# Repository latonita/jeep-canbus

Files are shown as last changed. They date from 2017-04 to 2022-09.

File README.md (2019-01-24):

# jeep-canbus  Analytics (https://github.com/igrigorik/ga-beacon) 

Projects around CAN BUS in Chrysler Jeep - VES enabler, other small features

PCB for Aux + bluetooth based on xs3868 v3.0 added.

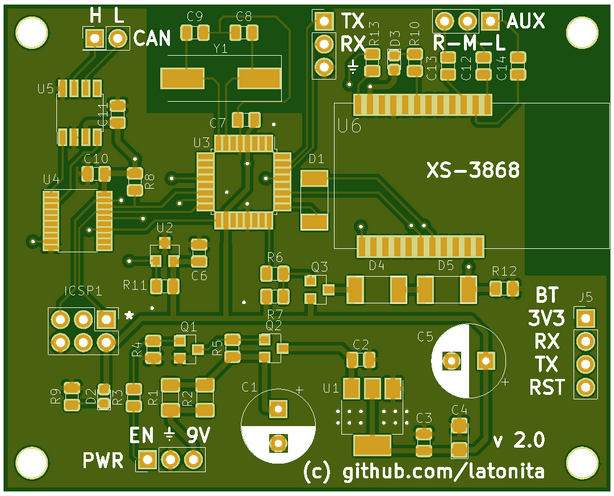
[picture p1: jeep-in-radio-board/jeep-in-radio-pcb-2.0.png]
PCBv2.0


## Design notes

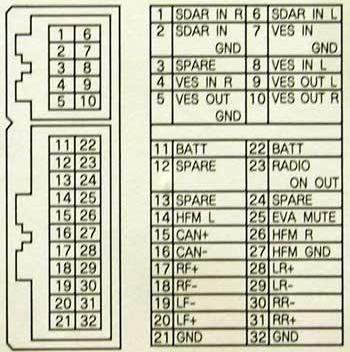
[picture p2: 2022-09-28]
jeep WH radio pinout.jpg

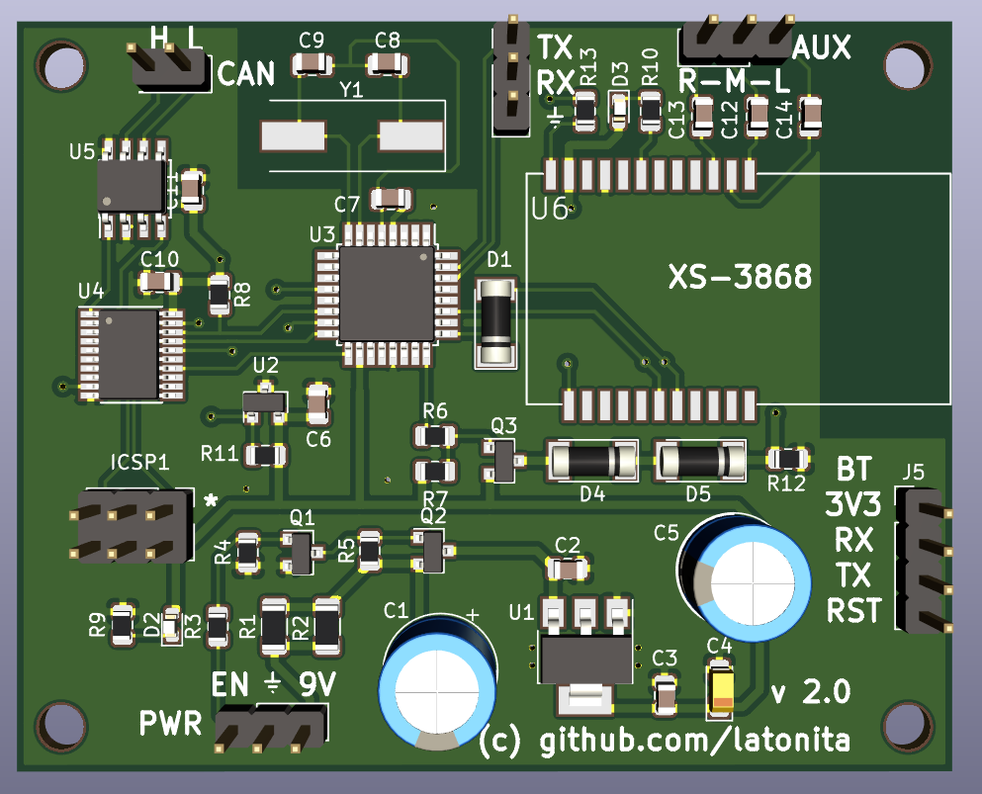
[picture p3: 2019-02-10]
jeep-in-radio-board/jeep-in-radio-pcb-2.1.png

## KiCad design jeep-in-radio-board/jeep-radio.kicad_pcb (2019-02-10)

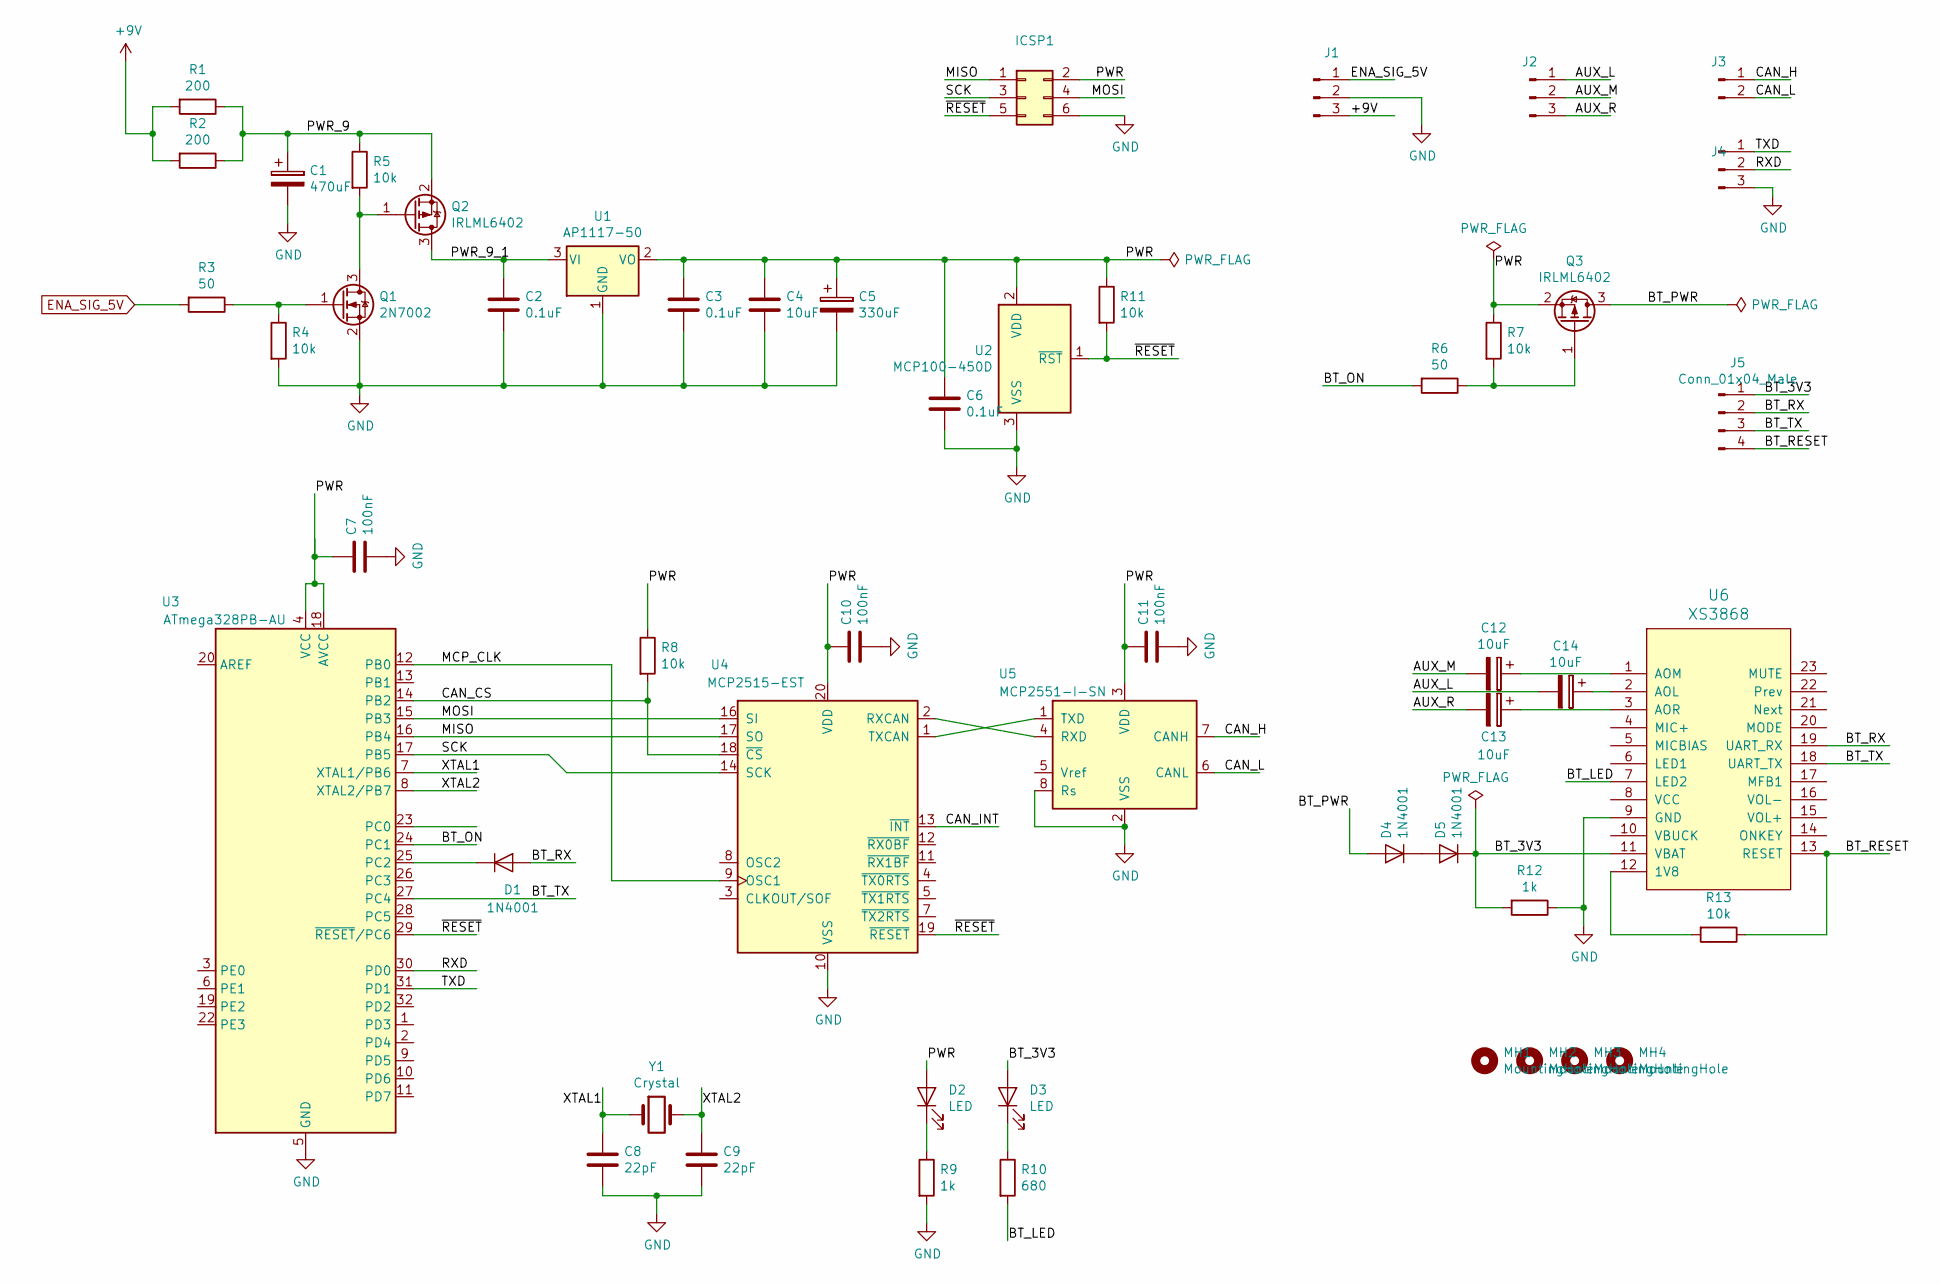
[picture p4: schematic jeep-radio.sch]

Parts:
C1: 470uF; CP_Radial_D8.0mm_P3.80mm
C2, C3, C6: 0.1uF; C_0805_2012Metric
C4: 10uF; CP_EIA-3216-18_Kemet-A
C5: 330uF; CP_Radial_D8.0mm_P3.80mm
C7, C10, C11: 100nF; C_0805_2012Metric
C8, C9: 22pF; C_0805_2012Metric
C12, C13, C14: 10uF; C_0805_2012Metric
D1, D4, D5: 1N4001; D_MELF
D2, D3: LED; LED_0603_1608Metric
ICSP1: Conn_02x03_Odd_Even; PinHeader_2x03_P2.54mm_Vertical
J1, J2, J4: Conn_01x03_Male; PinHeader_1x03_P2.54mm_Vertical
J3: Conn_01x02_Male; PinHeader_2x01_P2.54mm_Vertical
J5: Conn_01x04_Male; PinHeader_1x04_P2.54mm_Vertical
MH1, MH2, MH3, MH4: MountingHole; MountingHole_3.2mm_M3_DIN965
Q1: 2N7002; SOT-23
Q2, Q3: IRLML6402; SOT-23
R1, R2: 200; R_1206_3216Metric
R3, R6: 50; R_0805_2012Metric
R4, R5, R7, R8, R11, R13: 10k; R_0805_2012Metric
R9, R12: 1k; R_0805_2012Metric
R10: 680; R_0805_2012Metric
U1: AP1117-50; SOT-223-3_TabPin2
U2: MCP100-450D; SOT-23
U3: ATmega328PB-AU; TQFP-32_7x7mm_P0.8mm
U4: MCP2515-EST; TSSOP-20_4.4x6.5mm_P0.65mm
U5: MCP2551-I-SN; SOIC-8_3.9x4.9mm_P1.27mm
U6: XS3868
Y1: Crystal; Crystal_SMD_HC49-SD

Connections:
+9V: J1.3, R1.2, R2.2
/AUX_L: C14.2, J2.1
/AUX_M: C12.2, J2.2
/AUX_R: C13.2, J2.3
/BT_3V3: D3.2 (A), D5.1 (K), J5.1, R12.2, U6.11 (VBAT)
/BT_LED: R10.2, U6.7 (LED2)
/BT_ON: R6.2, U3.24 (PC1)
/BT_PWR: D4.2 (A), Q3.3 (D)
/BT_RESET: J5.4, R13.1, U6.13 (RESET)
/BT_RX: D1.2 (A), J5.2, U6.19 (UART_RX)
/BT_TX: J5.3, U3.27 (PC4), U6.18 (UART_TX)
/CAN_CS: R8.2, U3.14 (PB2), U4.18 (~CS)
/CAN_H: J3.1, U5.7 (CANH)
/CAN_INT: U4.13 (~INT)
/CAN_L: J3.2, U5.6 (CANL)
/MCP_CLK: U3.12 (PB0), U4.9 (OSC1)
/MISO: ICSP1.1, U3.16 (PB4), U4.17 (SO)
/MOSI: ICSP1.4, U3.15 (PB3), U4.16 (SI)
/PWR: C3.1, C4.1, C5.1, C6.1, C7.1, C10.1, C11.1, D2.2 (A), ICSP1.2, Q3.2 (S), R7.1, R8.1, R11.1, U1.2 (VO), U2.2 (VDD), U3.4 (VCC), U3.18 (AVCC), U4.20 (VDD), U5.3 (VDD)
/PWR_9: C1.1, Q2.2 (S), R1.1, R2.1, R5.1
/PWR_9_1: C2.1, Q2.3 (D), U1.3 (VI)
/RXD: J4.2, U3.30 (PD0)
/SCK: ICSP1.3, U3.17 (PB5), U4.14 (SCK)
/TXD: J4.1, U3.31 (PD1)
/XTAL1: C8.1, U3.7 (XTAL1/PB6), Y1.1
/XTAL2: C9.1, U3.8 (XTAL2/PB7), Y1.2
/~RESET~: ICSP1.5, R11.2, U2.1 (~RST), U3.29 (~RESET~/PC6), U4.19 (~RESET)
ENA_SIG_5V: J1.1, R3.2
GND: C1.2, C2.2, C3.2, C4.2, C5.2, C6.2, C7.2, C8.2, C9.2, C10.2, C11.2, ICSP1.6, J1.2, J4.3, Q1.2 (S), R4.2, R9.2, R12.1, U1.1 (GND), U2.3 (VSS), U3.5 (GND), U3.21 (GND), U4.10 (VSS), U5.2 (VSS), U5.8 (Rs), U6.9 (GND)
unnamed: C12.1, U6.1 (AOM)
unnamed: C13.1, U6.3 (AOR)
unnamed: C14.1, U6.2 (AOL)
unnamed: D1.1 (K), U3.25 (PC2)
unnamed: D2.1 (K), R9.1
unnamed: D3.1 (K), R10.1
unnamed: D4.1 (K), D5.2 (A)
unnamed: Q1.1 (G), R3.1, R4.1
unnamed: Q1.3 (D), Q2.1 (G), R5.2
unnamed: Q3.1 (G), R6.1, R7.2
unnamed: R13.2, U6.12 (1V8)
unnamed: U4.1 (TXCAN), U5.1 (TXD)
unnamed: U4.2 (RXCAN), U5.4 (RXD)

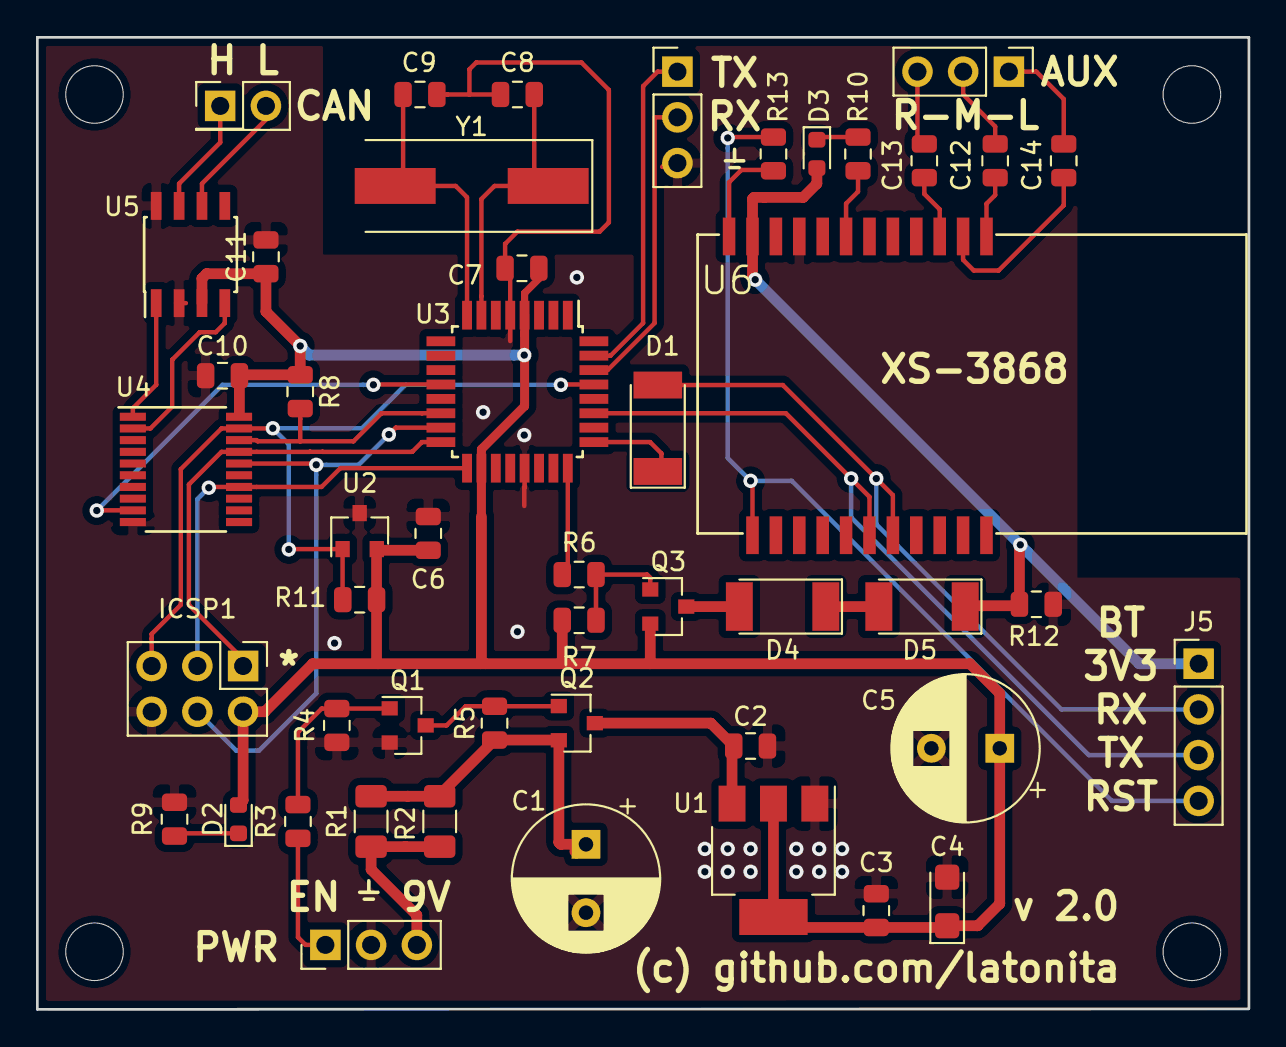
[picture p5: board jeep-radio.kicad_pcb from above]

Board: 2 copper layers, 67.3 x 54.0 mm, 52 parts (0 on the bottom side), 41 nets.

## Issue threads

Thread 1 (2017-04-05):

Auto low beam

latonita, 2017-04-05:
Turn on low beam automatically when engine is running.

Will help fix my broken multi switch connector :) Wires teared down and sometimes ECU thinks it is in "lights off" position.

Need to spam light messages overriding cluster (looks like it is possible).
Make sure not to override High Beam.

Read switch position -> spam to can bus.

Closed 2022-10-05.

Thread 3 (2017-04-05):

Add SLCAN enabled by pin

latonita, 2017-04-05:
For optional sniffing of can-bus traffic without removing module.

1. Add pin to ext connector
2. pull it down to make module sending all received packets to serial
3. release to stop

4. sending can messages is optional but very nice to have
5. hardcode all settings

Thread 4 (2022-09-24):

Wiring

developerfromjokela, 2022-09-24:
Hello!

How do you actually wire this in and get AUX working?

latonita, 2022-09-28:
Not really sure I got the question, but most of signals come from the wide connector on the back of the radio unit.
I have just soldered wires from inside of the radio to that connector. I can't tell exact pinout at the moment, you might need to google it.
So...
1. CAN H/CAN L - from the wide connector, pins 15,16
2. AUX IN R/L - also on the wide connector, pins 4 & 8. (VES IN R/L), pin 7  VES IN GND
3. Power - similar
4. for my super-overengineered with extra features
4.1. I also use some signal which took somewhere on the left part of the board which indicates whether radio in turned on or off by the left knob - this is used to turn on my MCU and bluetooth module to avoid any issues/glitches
4.2. on a can bus i also listen whether next/prev track button is pressed

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

developerfromjokela, 2022-09-28:
Yes it does.

Is the Can bus + High or low cable of canbus?

latonita, 2022-09-29:
Apologies :) Terminology differs a bit in different documents. Typically they use HIGH/LOW but on this picture they put + and - instead of H and L
So basically CAN+, CAN HIGH, CAN H refers to the same.
Similarly -> CAN-, CAN LOW, CAN L are the same thing.

Closed 2022-10-05.

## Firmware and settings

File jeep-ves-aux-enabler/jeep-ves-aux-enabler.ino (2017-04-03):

/*****************************************************************************************
*
* Hack for my Jeep Grand Cherokee WH 2006 (european) + RAR radio head unit
*
* My hardware:
*  1. Arduino Pro Mini 5v/16Mhz
*  2. Mcp2515_can SPI module (8Mhz)
*
* Features:
*  1. Bench mode to enable radio functioning while removed from the car 
*  2. Emulating VES presense to enable AUX IN in head unit
*
* Copyright (C) 2015-2017 Anton Viktorov <latonita@yandex.ru>
*                                    https://github.com/latonita/jeep-canbus
*
* This is free software. You may use/redistribute it under The MIT License terms.
*
*****************************************************************************************/
#include <SPI.h>
#include "mcp_can.h"

#define CAN_MODULE_CS_PIN 10

#define CHECK_PERIOD_MS 200
#define ANNOUNCE_PERIOD_MS 500
#define BUTTON_PRESS_DEBOUNCE_MS 350

#define BENCH_MODE_ON // When radio is removed from the car it needs to receive power-on message regularly so it thinks key is on

MCP_CAN CAN(CAN_MODULE_CS_PIN);

unsigned long lastAnnounce = 0;

unsigned char msgVesAuxMode[8] = {3,0,0,0,0,0,0,0};

#ifdef BENCH_MODE_ON
unsigned char msgPowerOn[6]= {0x63,0,0,0,0,0};
#endif

#define RADIOMODE_OTHER 0
#define RADIOMODE_AUX 1
unsigned char radioMode = RADIOMODE_OTHER;

void setup() {
  Serial.begin(115200);
  Serial.println("Jeep VES Enabler by latonita v.1.0");

  // My Jeep 2006 uses low-speed interior can bus 83.3kbps. Newer models use 125kbps for interior can-b bus and call it 'high-speed'
  // I use 8MHz mcp2515_can SPI module, had to update mcp_can lib to be able to work with lower freq. originally is works only with 16MHz modules
  while(CAN_OK != CAN.begin(CAN_83K3BPS, MCP_8MHz)) {
    Serial.println("CAN init fail");
    delay(250);
  }
  Serial.println("CAN init ok");
}

void sendAnnouncements() {
#ifdef BENCH_MODE_ON
    // when on bench - send power on command to radio to enable it
    CAN.sendMsgBuf(0x0, 0, 6, msgPowerOn);
    delay(25);
#endif
    //tell them VES AUX is here
    CAN.sendMsgBuf(0x3dd, 0, 8, msgVesAuxMode);
    delay(25);
}

void checkIncomingMessages() {
  static unsigned int canId = 0;
  static unsigned char len = 0;
  static unsigned char buf[8];
  static unsigned char oldMode = radioMode;
  if(CAN_MSGAVAIL == CAN.checkReceive()) {
    CAN.readMsgBuf(&len, buf);
  }
  canId = CAN.getCanId();

  switch (canId) {
    case 0x09f:
      // current radio mode
      radioMode = (buf[0] & 0xF == 6) ? RADIOMODE_AUX : RADIOMODE_OTHER;

      if (oldMode != radioMode) {
        if (radioMode == RADIOMODE_AUX) {
          Serial.print("Radio Mode changed to AUX");
        } else {
          Serial.print("Radio Mode changed to something else");
        }
      }
      break;

    default:
      break;
  }
}
void loop() {
  if (millis() > lastAnnounce + ANNOUNCE_PERIOD_MS) {
    lastAnnounce = millis();
    sendAnnouncements();
  }
  checkIncomingMessages();
}

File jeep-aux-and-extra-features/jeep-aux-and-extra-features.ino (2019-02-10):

/*****************************************************************************************
 *
 * Hack for my Jeep Grand Cherokee WH 2006 (european) + RAR radio head unit
 *
 * My hardware:
 *  1. Arduino Pro Mini 5v/16Mhz
 *  2. Mcp2515_can SPI module (8Mhz)
 *  3. Generic (H166) bluetooth A2DP module based on OVC3860, UART connected to Arduino
 *
 * Features:
 *  1. Bench mode to enable radio functioning while removed from the car
 *  2. Emulating VES presense to enable AUX IN in head unit
 *  2.1. Turn on/off BT A2DP module only when AUX IN is selected
 *  3. Control BT audio source with seek buttons
 *  4. [todo] Signal comfort module - blinkers blink three times instead of one.
 *  5. [todo] Headlights - always on
 *  6. [todo] Auto wipers - require installation of rain sensor (? maybe it will work alone, w/o my software :)
 *  7. [todo] Auto parameters display
 *  7.1. gasoline cost for a trip
 *
 * Copyright (C) 2015-2017 Anton Viktorov <latonita@yandex.ru>
 *                                    https://github.com/latonita/jeep-canbus
 *
 * This is free software. You may use/redistribute it under The MIT License terms.
 *
 *****************************************************************************************/
#include <SoftwareSerial.h>
#include <SPI.h>
#include "mcp_can.h"

#define CAN_MODULE_CS_PIN 10 // PB2

#define BLUETOOTH_SWITCH A1 // 15 //PC1

// BT TX -------- RX A4(18)
// BT RX -- >|--- TX A2(19)
// My BT module is 3.3v, but arduino is 5v.
// Need to put blocking diode: do not let Arduinos 5v get to BT, but let it easily pulldown a line
// Any diode with low Vf will do. In my case I put Schottky IN5819 desoldered from some dead device
#define BLUETOOTH_TX A4
#define BLUETOOTH_RX A2
SoftwareSerial btSerial(BLUETOOTH_TX, BLUETOOTH_RX);

#define CHECK_PERIOD_MS 200
#define ANNOUNCE_PERIOD_MS 500
#define BUTTON_PRESS_DEBOUNCE_MS 350

#define CAN_DELAY_AFTER_SEND 20

//#define BENCH_MODE_ON

MCP_CAN CAN(CAN_MODULE_CS_PIN);

unsigned long lastCheck = 0;
unsigned long lastAnnounce = 0;
unsigned long lastButtonPress = 0;

#define msgVesAuxModeLen 8
unsigned char msgVesAuxMode[8] = {3, 0, 0, 0, 0, 0, 0, 0};

#ifdef BENCH_MODE_ON
#define msgPowerOnLen 6
unsigned char msgPowerOn[6] = {0x63, 0, 0, 0, 0, 0};
#endif

#define RADIOMODE_OTHER 0
#define RADIOMODE_AUX 1
unsigned char radioMode = RADIOMODE_OTHER;

const char compileDate[] = __DATE__ " " __TIME__;

#define PIN_DOWN(x)                                                                                                                                  \
  pinMode(x, OUTPUT);                                                                                                                                \
  digitalWrite(x, LOW);

void pinsSetup() {
  /*  PIN_DOWN(2);
    PIN_DOWN(3);
    PIN_DOWN(4);
    PIN_DOWN(5);
    PIN_DOWN(6);
    PIN_DOWN(7);
    PIN_DOWN(8);
    PIN_DOWN(9);
  */
  pinMode(BLUETOOTH_SWITCH, OUTPUT);
  digitalWrite(BLUETOOTH_SWITCH, LOW);
}

#define CAN_POWER 0x000
#define CAN_BLINKERS 0x006
#define CAN_RADIO_MODE 0x09f
#define CAN_RADIO_CONTROLS 0x394
#define CAN_VES_UNIT 0x3dd

//#define CAN_MULTI_SWITCH   0x11d
//#define CAN_HEADLIGHTS 0x1c8

// void setupFilters() {
//  CAN.init_Mask(0, 0, 0x3ff);
//  CAN.init_Mask(1, 0, 0x3ff);
//
//  CAN.init_Filt(0, 0, CAN_POWER);
//  CAN.init_Filt(1, 0, CAN_RADIO_MODE);
//  CAN.init_Filt(2, 0, CAN_RADIO_CONTROLS);
//  CAN.init_Filt(3, 0, CAN_BLINKERS);
//  CAN.init_Filt(4, 0, 0x08);
//  CAN.init_Filt(5, 0, 0x09);
//}

void setup() {
  //  pinsSetup();

  Serial.begin(115200);
  Serial.print("Jeep VES Enabler + Extras by latonita v.1.1, ");
  Serial.println(compileDate);

  btSerial.begin(115200);

  while (CAN_OK != CAN.begin(CAN_83K3BPS, MCP_8MHz)) {
    Serial.println("CAN init fail");
    delay(250);
  }
  Serial.println("CAN init ok");

  // TODO: set hardware filter to minimize number messages which come through
  // setupFilters();
}

void sendAnnouncements() {
#ifdef BENCH_MODE_ON
  // when on bench - send power on command to radio to enable it
  CAN.sendMsgBuf(CAN_POWER, 0, msgPowerOnLen, msgPowerOn);
  delay(CAN_DELAY_AFTER_SEND);
#endif
  // tell them VES AUX is here
  CAN.sendMsgBuf(CAN_VES_UNIT, 0, msgVesAuxModeLen, msgVesAuxMode);
  delay(CAN_DELAY_AFTER_SEND);
}

unsigned int canId = 0;
unsigned char len = 0;
unsigned char buf[8];
unsigned char newMode = 0;

void checkIncomingMessages() {

  if (CAN_MSGAVAIL != CAN.checkReceive())
    return;

  CAN.readMsgBuf(&len, buf);
  canId = CAN.getCanId();

  switch (canId) {
  case CAN_RADIO_MODE:

    // some debug output
    Serial.print("CAN ID: ");
    Serial.print(canId, HEX);

    for (int i = 0; i < len; i++) {
      Serial.print(",");
      Serial.print(buf[i], HEX);
    }
    Serial.println();
    Serial.print("Radio mode: ");
    Serial.print(buf[0] & 0xF, HEX);
    Serial.print(":");
    Serial.print(radioMode);
    Serial.print(">");
    Serial.println(newMode);

    newMode = ((buf[0] & 0xF) == 6) ? RADIOMODE_AUX : RADIOMODE_OTHER;

    if (radioMode != newMode) {
      radioMode = newMode;
      digitalWrite(BLUETOOTH_SWITCH, radioMode == RADIOMODE_AUX ? HIGH : LOW);
      if (radioMode == RADIOMODE_AUX) {
        Serial.print("Radio Mode changed to AUX");
      } else {
        Serial.print("Radio Mode changed to something else");
      }
    }
    break;
  case CAN_RADIO_CONTROLS:
    // radio mode + buttons
    if (buf[3] > 0 && millis() > lastButtonPress + BUTTON_PRESS_DEBOUNCE_MS) { // something pressed
      lastButtonPress = millis();
      if (buf[3] & 1) { // seek right
        Serial.println("-- Seek >>");
        Serial.write("AT#MD\n\r");
        btSerial.write("AT#MD\n\r");
      } else if (buf[3] & 2) { // seek left
        Serial.println("<< Seek --");
        Serial.write("AT#ME\n\r");
        btSerial.write("AT#ME\n\r");
      } else if (buf[3] & 4) { // rw/ff right
        Serial.println("-- RW FF >>");
      } else if (buf[3] & 8) { // rw/ff left
        Serial.println("<< RW FF --");
      } else if (buf[3] & 0x20) { // RND/PTY
        Serial.println("[RND/PTY] - use as play/pause");
        Serial.write("AT#MA\n\r");
        btSerial.write("AT#MA\n\r");
      }
    }

  default:
    break;
  }
}
void loop() {
  if (millis() > lastAnnounce + ANNOUNCE_PERIOD_MS) {
    lastAnnounce = millis();
    sendAnnouncements();
  }
  checkIncomingMessages();
}

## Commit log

2017-04-03 Bug fixes + travis.ci
    [jeep-aux-and-extra-features.ino]
2018-09-10 schematics 0.1
    [jeep-radio.sch]
2018-09-10 ver 1
    [jeep-radio.kicad_pcb, jeep-radio.sch]
2018-09-10 ver 1.001
    [jeep-radio.kicad_pcb]
2018-11-27 PCB for xs3868v3
    [jeep-radio-B.Cu.gbr, jeep-radio-B.Mask.gbr, jeep-radio-B.Paste.gbr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]
2018-11-27 pic of pcb
2019-02-09 pcb to be fixed with new xs3868 footprint
    [jeep-radio.kicad_pcb]
2019-02-10 pcb fix
    [jeep-radio.kicad_pcb]
2019-02-10 pcb fix, sw pins update
    [jeep-radio-B.Cu.gbr, jeep-radio-B.Mask.gbr, jeep-radio-B.SilkS.gbr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]
2019-02-10 updated gerbers 2.1
    [jeep-radio-B.Cu.gbr, jeep-radio-B.Mask.gbr, jeep-radio-B.SilkS.gbr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]
2026-09-13 carputer: live dashboard on the WK, broadcasts + TPMS
    First build that reads the real vehicle. Five swipeable pages on the
    240x320 panel, fed by passive CAN-B monitoring with KWP requests only
    for what the bus never broadcasts.
    Protocol fix that unblocked everything: kwpBuildReadLocalId() emitted
    the service byte twice for a service-qualified id, so 0x213E went out
    as `21 21 3E` and no module ever answered. Every recorded capture shows
    `21 3E`. Regression test added.
    Data:
    - passive ATMA monitor window feeds RPM, speed, coolant, ambient,
    voltage, odometer, ignition, dimmer and lights at bus rate
    - KWP polls reduced to what is request-only: tyre pressures, fuel %,
    warning lamps, fluid f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
